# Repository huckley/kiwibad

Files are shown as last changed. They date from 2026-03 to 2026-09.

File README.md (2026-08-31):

# Temperatur Messung im Kiwibad
misst aller halben Stunde die Temperatur und versendet sie via LoRa, export der historischen Daten via BLE ans Smartphone über [phyphox](https://phyphox.org/)
### Sender 
* Vision Master E213
* [GT-U7 GPS-Modul](https://de.aliexpress.com/item/1005001713388717.html)
* [10 Paar 3 Pin SM JST 15 cm Kabel Buchse/Stecker](https://de.aliexpress.com/item/1005006673736507.html)
* 2x [3400 mAh 18650 Lithium-Akku](https://de.aliexpress.com/item/1005007281673163.html)
* [115x90x55mm wasserdichtes Gehäuse](https://de.aliexpress.com/item/1005005631937759.html)
* [SP1710P SP1712S 5 Pin](https://de.aliexpress.com/item/1005006892125866.html)
* [4 18650 Parallele Batteriebox](https://de.aliexpress.com/item/1005001955162216.html)
* [DS18B20 10m](https://de.aliexpress.com/item/1005006090368473.html)
* [DS18B20 1m](https://de.aliexpress.com/item/1005006090368473.html)
### Empfänger
* Heltec WiFi LoRa 32(V3)
* acos-ht4 3dprints are copys from https://www.printables.com/model/1519914-heltec-lora-32-v4v3-pocket-pager-case [CC BY-SA 4.0.]( https://creativecommons.org/licenses/by-sa/4.0/) [@AlleyCat](https://www.printables.com/@AlleyCat)

## Export der historischen Daten am Empfänger
1. [App installieren](https://phyphox.org/)
2. Oben rechts das Plus-Symbol
3. Neues Experiment für Bluetooth-Gerät
4. Kiwibad auswählen
5. auf den Playbutton drücken

## Build instructions

arduino with
* version 2.1.5 of https://github.com/HelTecAutomation/Heltec_ESP32
* https://github.com/Heltec-Aaron-Lee/WiFi_Kit_series [last version has bug](https://github.com/Heltec-Aaron-Lee/WiFi_Kit_series/issues/296)
* Vision Master E213 (sender)
* Heltec WiFi LoRa 32(V3) (receiver)

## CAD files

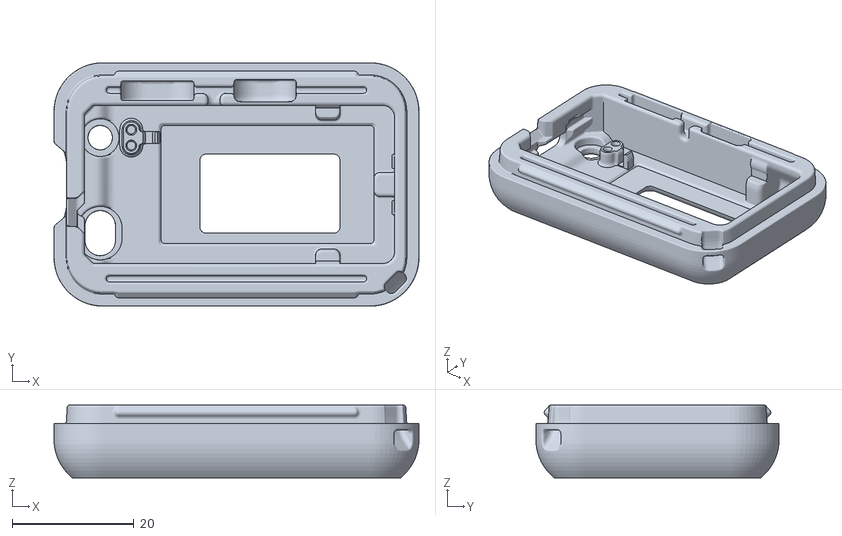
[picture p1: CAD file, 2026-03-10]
3dprint/acos-ht4-pocket-front.stl
60.0 x 40.0 x 12.0

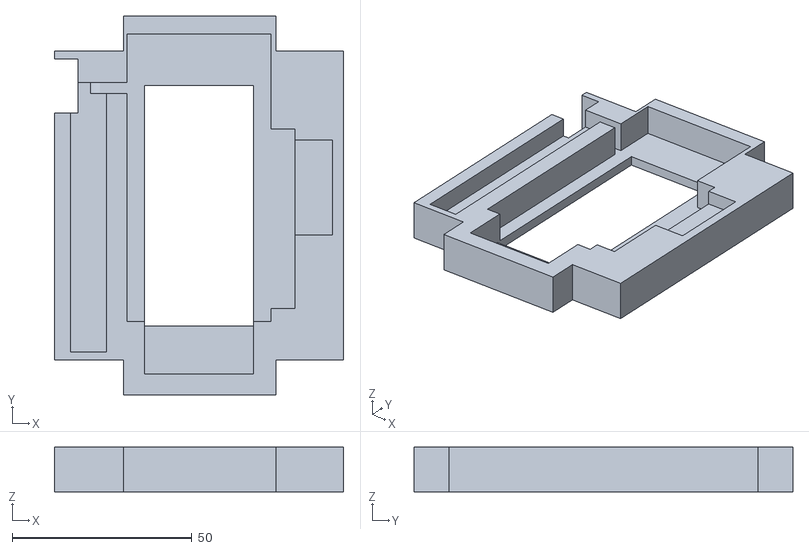
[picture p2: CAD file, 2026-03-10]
3dprint/Kiwigehäuse_front.stl
80.5 x 105.5 x 12.5

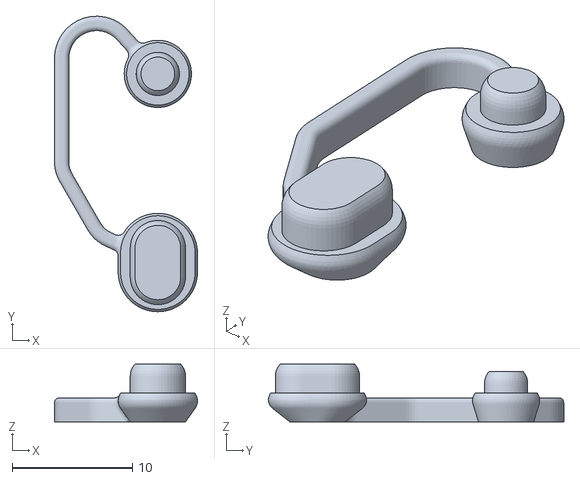
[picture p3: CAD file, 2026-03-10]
3dprint/acos-ht4-buttons.stl
11.9 x 24.6 x 4.80

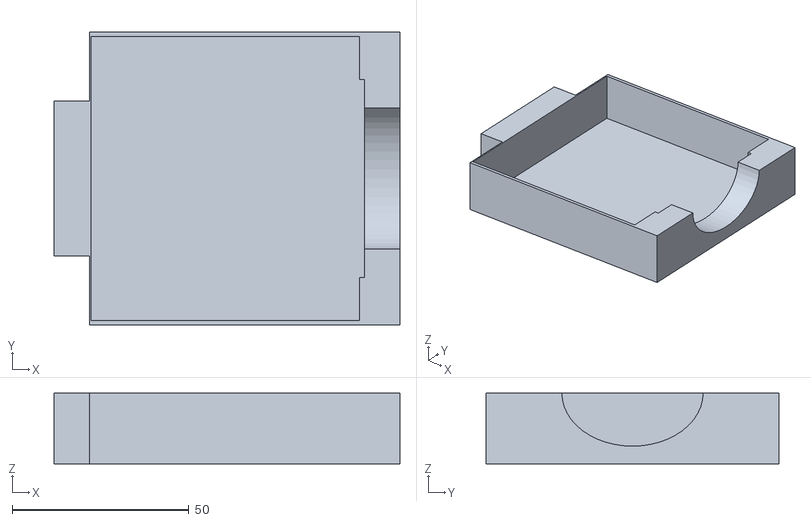
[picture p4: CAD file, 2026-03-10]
3dprint/Kiwigehäuse_bottom.stl
98.0 x 83.0 x 20.0

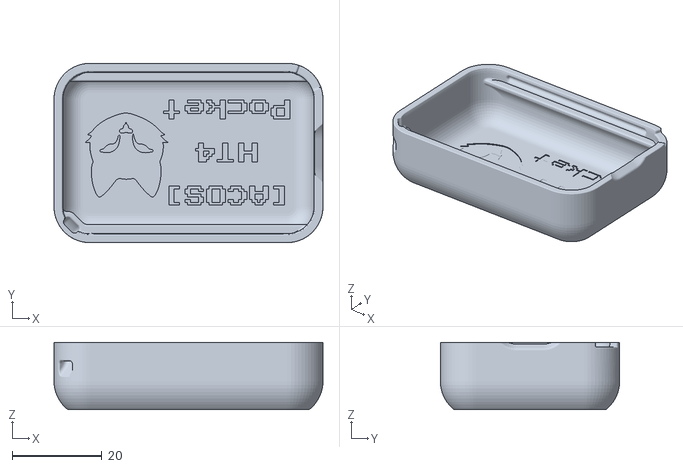
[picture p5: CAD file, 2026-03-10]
3dprint/acos-ht4-pocket-back.stl
60.0 x 40.0 x 15.0

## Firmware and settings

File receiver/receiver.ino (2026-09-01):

#include "LoRaWan_APP.h"
#include "Arduino.h"
#include "HT_SSD1306Wire.h"
#include <time.h>
#include "../secret.h"
#include "../lora.h"
#include "esp_wifi.h"     // ESP32 WiFi control (power saving)
#include "../sensors.h"

// ==== phyphox BLE (nativ, ohne phyphoxBLE-Bibliothek) ====
// Zwei GATT-Services:
//  1) Der offizielle phyphox-Service (UUID cddf0001-...). Wird beworben,
//     damit das Geraet im Bluetooth-Scan von phyphox direkt "weiss"
//     (=unterstuetzt) erscheint. Ueber die Characteristics 0002/0003
//     liefert der Receiver die komplette Experiment-Konfiguration
//     (siehe PHYPHOX_XML unten) automatisch an die App - kein manuelles
//     Laden einer .phyphox-Datei, kein QR-Code noetig.
//     Protokoll: https://phyphox.org/wiki/index.php/Bluetooth_Low_Energy
//     (Abschnitt "Sending phyphox-files from a device")
//  2) Ein eigener Service fuer die eigentlichen Messwerte (6b6a0001-...),
//     auf den die oben gelieferte Konfiguration verweist.
#include <BLEDevice.h>
#include <BLEServer.h>
#include <BLEUtils.h>
#include <BLE2902.h>

#define BLE_DEVICE_NAME "Kiwibad"

#define PHYPHOX_SERVICE_UUID     "cddf0001-30f7-4671-8b43-5e40ba53514a"
#define PHYPHOX_EXPERIMENT_UUID  "cddf0002-30f7-4671-8b43-5e40ba53514a" // liefert die Konfiguration
#define PHYPHOX_CONTROL_UUID     "cddf0003-30f7-4671-8b43-5e40ba53514a" // App schreibt 1 = "sende jetzt"

#define KIWIBAD_DATA_SERVICE_UUID "6b6a0001-1c7c-4d69-9d2b-3a2e6f9a1000"
#define KIWIBAD_DATA_CHAR_UUID    "6b6a0002-1c7c-4d69-9d2b-3a2e6f9a1000"

// Identisch zu Kiwibad.phyphox im Repo (dort nur als lesbares Backup/Referenz -
// diese eingebettete Kopie ist die, die tatsaechlich an die App geschickt wird).
static const char PHYPHOX_XML[] =
R"PHYPHOXFILE(<phyphox version="1.7">
    <title>Kiwibad Temperatur</title>
    <category>Kiwibad</category>
    <color>ff8000</color>
    <description>
        Luft- und Wassertemperatur (je 2 Sensoren) sowie Batteriespannung aus
        dem Kiwibad, per LoRa empfangen. Der Receiver liefert dieses
        Experiment automatisch per Bluetooth mit - kein manuelles Laden
        einer Datei noetig, einfach im Bluetooth-Scan antippen.
        Zeigt zuerst die gespeicherte Historie (bis zu 24 Messungen), danach
        neue Messungen live.
        X-Achse: Uhrzeit in Dezimalstunden (z.B. 8.5 = 08:30 Uhr).
        Ein Sensor, der noch nie gemeldet wurde, liefert -127°C (dieselbe
        Fehlerkonvention wie beim DS18B20-Sensor selbst) - diese Punkte
        werden in den Graphen per Filter entfernt (echte Luecke statt
        Ausreisser).
    </description>

    <data-containers>
        <container size="500">recordTimeHours</container>
        <container size="500">air1Temp</container>
        <container size="500">air2Temp</container>
        <container size="500">water1Temp</container>
        <container size="500">water2Temp</container>
        <container size="500">batteryMilliVolts</container>
        <container size="500">air1TempF</container>
        <container size="500">air1TimeF</container>
        <container size="500">air2TempF</container>
        <container size="500">air2TimeF</container>
        <container size="500">water1TempF</container>
        <container size="500">water1TimeF</container>
        <container size="500">water2TempF</container>
        <container size="500">water2TimeF</container>
    </data-containers>

    <input>
        <bluetooth name="Kiwibad" uuid="cddf0001-30f7-4671-8b43-5e40ba53514a" id="kiwibad" autoConnect="true" mode="notification" subscribeOnStart="false">
            <output char="6b6a0002-1c7c-4d69-9d2b-3a2e6f9a1000" conversion="float32LittleEndian" offset="0" size="4">recordTimeHours</output>
            <output char="6b6a0002-1c7c-4d69-9d2b-3a2e6f9a1000" conversion="int8" offset="4" size="1">air1Temp</output>
            <output char="6b6a0002-1c7c-4d69-9d2b-3a2e6f9a1000" conversion="int8" offset="5" size="1">air2Temp</output>
            <output char="6b6a0002-1c7c-4d69-9d2b-3a2e6f9a1000" conversion="int8" offset="6" size="1">water1Temp</output>
            <output char="6b6a0002-1c7c-4d69-9d2b-3a2e6f9a1000" conversion="int8" offset="7" size="1">water2Temp</output>
            <output char="6b6a0002-1c7c-4d69-9d2b-3a2e6f9a1000" conversion="uInt16LittleEndian" offset="8" size="2">batteryMilliVolts</output>
        </bluetooth>
    </input>

    <analysis>
        <rangefilter>
            <input clear="false">air1Temp</input>
            <input as="min" type="value">-50</input>
            <input as="max" type="value">100</input>
            <input clear="false">recordTimeHours</input>
            <output>air1TempF</output>
            <output>air1TimeF</output>
        </rangefilter>
        <rangefilter>
            <input clear="false">air2Temp</input>
            <input as="min" type="value">-50</input>
            <input as="max" type="value">100</input>
            <input clear="false">recordTimeHours</input>
            <output>air2TempF</output>
            <output>air2TimeF</output>
        </rangefilter>
        <rangefilter>
            <input clear="false">water1Temp</input>
            <input as="min" type="value">-50</input>
            <input as="max" type="value">100</input>
            <input clear="false">recordTimeHours</input>
            <output>water1TempF</output>
            <output>water1TimeF</output>
        </rangefilter>
        <rangefilter>
            <input clear="false">water2Temp</input>
            <input as="min" type="value">-50</input>
            <input as="max" type="value">100</input>
            <input clear="false">recordTimeHours</input>
            <output>water2TempF</output>
            <output>water2TimeF</output>
        </rangefilter>
    </analysis>

    <views>
        <view label="Temperaturverlauf">
            <value label="Uhrzeit" unit="h" precision="2">
                <input>recordTimeHours</input>
            </value>
            <value label="Luft 1" unit="°C" precision="0" color="ff8000">
                <input>air1Temp</input>
            </value>
            <value label="Luft 2" unit="°C" precision="0" color="ffc080">
                <input>air2Temp</input>
            </value>
            <value label="Wasser 1" unit="°C" precision="0" color="0080ff">
                <input>water1Temp</input>
            </value>
            <value label="Wasser 2" unit="°C" precision="0" color="80c0ff">
                <input>water2Temp</input>
            </value>
            <value label="Batteriespannung" unit="mV" precision="0">
                <input>batteryMilliVolts</input>
            </value>

            <separator height="1" />

            <graph label="Lufttemperatur" labelX="Uhrzeit (h)" labelY="Temperatur" unitY="°C" partialUpdate="true">
                <input axis="x" color="ff8000">air1TimeF</input>
                <input axis="y" color="ff8000">air1TempF</input>
                <input axis="x" color="ffc080">air2TimeF</input>
                <input axis="y" color="ffc080">air2TempF</input>
            </graph>

            <graph label="Wassertemperatur" labelX="Uhrzeit (h)" labelY="Temperatur" unitY="°C" partialUpdate="true">
                <input axis="x" color="0080ff">water1TimeF</input>
                <input axis="y" color="0080ff">water1TempF</input>
                <input axis="x" color="80c0ff">water2TimeF</input>
                <input axis="y" color="80c0ff">water2TempF</input>
            </graph>

            <graph label="Batteriespannung" labelX="Uhrzeit (h)" labelY="Spannung" unitY="mV" partialUpdate="true">
                <input axis="x">recordTimeHours</input>
                <input axis="y">batteryMilliVolts</input>
            </graph>
        </view>
    </views>

    <export>
        <set name="Kiwibad Messwerte (roh, inkl. -127 = kein Wert)">
            <data name="Uhrzeit (Dezimalstunden)">recordTimeHours</data>
            <data name="Lufttemperatur 1 (°C)">air1Temp</data>
            <data name="Lufttemperatur 2 (°C)">air2Temp</data>
            <data name="Wassertemperatur 1 (°C)">water1Temp</data>
            <data name="Wassertemperatur 2 (°C)">water2Temp</data>
            <data name="Batteriespannung (mV)">batteryMilliVolts</data>
        </set>
        <set name="Kiwibad Messwerte (gefiltert)">
            <data name="Luft 1 - Uhrzeit">air1TimeF</data>
            <data name="Luft 1 - Temperatur (°C)">air1TempF</data>
            <data name="Luft 2 - Uhrzeit">air2TimeF</data>
            <data name="Luft 2 - Temperatur (°C)">air2TempF</data>
            <data name="Wasser 1 - Uhrzeit">water1TimeF</data>
            <data name="Wasser 1 - Temperatur (°C)">water1TempF</data>
            <data name="Wasser 2 - Uhrzeit">water2TimeF</data>
            <data name="Wasser 2 - Temperatur (°C)">water2TempF</data>
        </set>
    </export>
</phyphox>
)PHYPHOXFILE";

BLEServer *pBleServer = nullptr;
BLECharacteristic *pPhyphoxExperimentChar = nullptr; // 0002: liefert PHYPHOX_XML
BLECharacteristic *pPhyphoxControlChar = nullptr;     // 0003: App schreibt 1 = "sende jetzt"
BLECharacteristic *pKiwibadDataChar = nullptr;        // eigene Messwert-Characteristic
volatile bool bleClientConnected = false;

static BLE2902 phyphoxExperimentCCCD;
static BLE2902 kiwibadDataCCCD;

// === Nicht-blockierendes History-Replay (statt delay(30) in einer Schleife) ===
// tickHistoryReplay() wird aus loop() aufgerufen und schickt pro Aufruf
// hoechstens EINEN Eintrag - der naechste folgt erst wieder, wenn seit dem
// letzten Versand mindestens HISTORY_SEND_INTERVAL_MS vergangen sind.
const unsigned long HISTORY_SEND_INTERVAL_MS = 30;
bool historyReplayActive = false;
int historyReplayIndex = 0;
float historyFillAir[MAX_SENSORS];
float historyFillWater[MAX_SENSORS];
unsigned long historyLastSendTime = 0;

// Fallback, falls der CCCD-Subscribe-Callback aus irgendeinem Grund nicht
// zuverlaessig feuert (variiert je nach ESP32-BLE-Bibliotheksversion):
// solange verbunden, wird die Historie zusaetzlich in einem festen Intervall
// automatisch erneut geschickt - dann klappt es spaetestens danach von selbst,
// ganz ohne Tastendruck.
const unsigned long AUTO_HISTORY_RESEND_INTERVAL_MS = 5000;
unsigned long lastAutoHistorySend = 0;

// === Nicht-blockierende Uebertragung der phyphox-Experiment-Datei ===
const unsigned long FILE_CHUNK_INTERVAL_MS = 20;
const size_t FILE_CHUNK_SIZE = 18; // sicher unter der Standard-BLE-MTU von 20 Byte
volatile bool fileTransferRequested = false; // wird aus der BLE-Callback gesetzt
bool fileTransferActive = false;
bool fileTransferHeaderSent = false;
size_t fileTransferSent = 0;
unsigned long fileTransferLastChunkTime = 0;

// ==== OLED ====
SSD1306Wire oled_display(0x3c, 500000, SDA_OLED, SCL_OLED, GEOMETRY_128_64, RST_OLED);
#include "battery.h"

#define buttonPin 0
volatile bool buttonPressed = false;
unsigned long lastActivityTime = 0;
bool displayOn = true;
const unsigned long DISPLAY_TIMEOUT = 5 * 60 * 1000; // 5 Minuten in ms
volatile unsigned long lastButtonTime = 0; // Zeitstempel für Entprellung
const unsigned long DEBOUNCE_DELAY = 250; // 250ms Sperrzeit

// ISR für den Button
void IRAM_ATTR handleButton() {
  unsigned long currentTime = millis();
  // Nur akzeptieren, wenn der letzte Klick länger als DEBOUNCE_DELAY her ist
  if (currentTime - lastButtonTime > DEBOUNCE_DELAY) {
    buttonPressed = true;
    lastButtonTime = currentTime;
  }
}

typedef enum {
  LOWPOWER,
  STATE_RX
} States_t;
States_t state;

struct Measurement {
  uint8_t address1;
  uint8_t address2;
  uint8_t hour;
  uint8_t minute;
  float temperature1;
  float temperature2;
  float batteryVoltage;
};

const int MAX_ENTRIES = 24;
Measurement rrdBuffer[MAX_ENTRIES];
int head = 0;
int displayhead = 0;

void VextON() {
  pinMode(Vext, OUTPUT);
  digitalWrite(Vext, LOW);
}

void VextOFF() {
  pinMode(Vext, OUTPUT);
  digitalWrite(Vext, HIGH);
}

// === Sensor-Rohwerte den einzelnen physischen Sensoren zuordnen ===
// sensors.h definiert MAX_SENSORS (=2) Luft- UND 2 Wassersensoren mit fester
// Adresse. Ein LoRa-Paket trägt immer nur zwei Messwerte (addr1/temp1,
// addr2/temp2), aber über mehrere Pakete hinweg können unterschiedliche
// Sensoren gemeldet werden. Deshalb hier NICHT auf ein gemeinsames
// "airTemp"/"waterTemp" zusammenfassen, sondern jedem
// air_sensor_addr[i] / water_sensor_addr[i] seinen eigenen Kanal geben.
// Nicht in diesem Paket enthaltene Sensoren bleiben NAN.
void classifySensors(uint8_t addr1, uint8_t addr2, float temp1, float temp2,
                      float airTemps[MAX_SENSORS], float waterTemps[MAX_SENSORS]) {
  for (int i = 0; i < MAX_SENSORS; i++) {
    airTemps[i] = NAN;
    waterTemps[i] = NAN;
  }
  for (int i = 0; i < MAX_SENSORS; i++) {
    uint8_t airAddr = getshortaddr(air_sensor_addr[i]);
    if (addr1 == airAddr) airTemps[i] = temp1;
    if (addr2 == airAddr) airTemps[i] = temp2;

    uint8_t waterAddr = getshortaddr(water_sensor_addr[i]);
    if (addr1 == waterAddr) waterTemps[i] = temp1;
    if (addr2 == waterAddr) waterTemps[i] = temp2;
  }
}

// Ersten nicht-NAN Wert aus einem Array zurückgeben (fürs kleine OLED-Display,
// das nur Platz für einen einzelnen "L:"/"W:"-Wert hat)
float firstValid(float values[MAX_SENSORS]) {
  for (int i = 0; i < MAX_SENSORS; i++) {
    if (!isnan(values[i])) return values[i];
  }
  return NAN;
}

// === Einen Messpunkt an phyphox schicken ===
// Ein Paket, 10 Byte, little endian (siehe Kiwibad.phyphox):
//   Byte 0-3: Uhrzeit in Dezimalstunden (float32)
//   Byte 4  : Lufttemperatur 1, ganze °C (int8) - oder -127, wenn dieser
//             Sensor noch nie gemeldet wurde (dieselbe Fehlerkonvention wie
//             beim DS18B20 selbst, siehe OnRxDone weiter unten)
//   Byte 5  : Lufttemperatur 2, ganze °C (int8, -127 = kein Wert)
//   Byte 6  : Wassertemperatur 1, ganze °C (int8, -127 = kein Wert)
//   Byte 7  : Wassertemperatur 2, ganze °C (int8, -127 = kein Wert)
//   Byte 8-9: Batteriespannung in mV (uInt16)
const int8_t PHYPHOX_NO_VALUE = -127;

void sendMeasurementToPhyphox(uint16_t recordTime, float airTemps[MAX_SENSORS],
                               float waterTemps[MAX_SENSORS], float batV) {
  if (!bleClientConnected || pKiwibadDataChar == nullptr) {
    Serial.println("phyphox-Messwert NICHT gesendet: kein BLE-Client verbunden");
    return;
  }

  float recordTimeHoursF = (float)recordTime / 60.0f;

  int8_t airVals[MAX_SENSORS];
  int8_t waterVals[MAX_SENSORS];
  for (int s = 0; s < MAX_SENSORS; s++) {
    airVals[s]   = isnan(airTemps[s])   ? PHYPHOX_NO_VALUE : (int8_t)lroundf(airTemps[s]);
    waterVals[s] = isnan(waterTemps[s]) ? PHYPHOX_NO_VALUE : (int8_t)lroundf(waterTemps[s]);
  }
  uint16_t battMv = (uint16_t)lroundf(batV * 1000.0f);

  uint8_t packet[10];
  memcpy(&packet[0], &recordTimeHoursF, sizeof(float));
  packet[4] = (uint8_t)airVals[0];
  packet[5] = (uint8_t)airVals[1];
  packet[6] = (uint8_t)waterVals[0];
  packet[7] = (uint8_t)waterVals[1];
  packet[8] = battMv & 0xFF;
  packet[9] = (battMv >> 8) & 0xFF;

  pKiwibadDataChar->setValue(packet, sizeof(packet));
  pKiwibadDataChar->notify();

  Serial.printf("phyphox-Messwert gesendet: t=%.2f h, Luft1=%d Luft2=%d Wasser1=%d Wasser2=%d C, Batt=%u mV\n",
                recordTimeHoursF, airVals[0], airVals[1], waterVals[0], waterVals[1], battMv);
}

// === Kompletten Ringpuffer (älteste zuerst) an phyphox schicken ===
// Ein LoRa-Paket liefert immer nur 2 der 4 Sensoren - deshalb wird hier beim
// Durchlaufen fortgeschrieben (letzter bekannter Wert bleibt stehen, statt
// bei jedem Eintrag auf 2 von 4 Linien eine Lücke zu erzeugen).
//
// Nicht-blockierend: startHistoryReplay() setzt nur den Startzustand,
// tickHistoryReplay() (aus loop() aufgerufen) schickt pro Aufruf höchstens
// einen Eintrag und pausiert dazwischen per millis()-Vergleich statt delay().
void startHistoryReplay() {
  for (int s = 0; s < MAX_SENSORS; s++) {
    historyFillAir[s] = NAN;
    historyFillWater[s] = NAN;
  }
  historyReplayIndex = 0;
  historyReplayActive = true;
  historyLastSendTime = 0; // naechster tick darf sofort senden
}
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
void loop() {
  // Fallback-Trigger: alle paar Sekunden automatisch erneut senden, solange
  // verbunden - unabhaengig davon, ob der CCCD-Subscribe-Callback zuverlaessig
  // gefeuert hat. Kein delay(): reiner millis()-Vergleich.
  if (bleClientConnected && !historyReplayActive &&
      (millis() - lastAutoHistorySend >= AUTO_HISTORY_RESEND_INTERVAL_MS)) {
    startHistoryReplay();
    lastAutoHistorySend = millis();
  }

  if (buttonPressed) {
    buttonPressed = false;
    lastActivityTime = millis(); // Timer resetten

    if (!displayOn) {
      VextON();
      oled_display.init();
      displayOn = true;
    } else {
      // Rückwärts durch den Buffer blättern
      displayhead = (displayhead - 1 + MAX_ENTRIES) % MAX_ENTRIES;
    }
    updateDisplay(displayhead);
    startHistoryReplay(); // Taste dient auch als manuelles "jetzt an phyphox senden"
  }

  // Nicht-blockierende BLE-Zustandsautomaten - schicken pro Aufruf höchstens
  // ein Paket und kehren sofort zurück, kein delay() irgendwo im Ablauf.
  tickHistoryReplay();
  tickPhyphoxFileTransfer();

  // 2. Timeout Check (Display aus nach 5 Min)
  /*
  if (displayOn && (millis() - lastActivityTime > DISPLAY_TIMEOUT)) {
    oled_display.clear();
    oled_display.display();
    // Vext ausschalten spart am Heltec Board am meisten Strom
    VextOFF();
    displayOn = false;
  }
  */

  switch (state) {
    case STATE_RX:
      Radio.Rx(0); // Listen for packets
      state = LOWPOWER;
      break;
    case LOWPOWER:
      Radio.IrqProcess(); // Check LoRa events
      break;
    default:
      break;
  }
}

// === OLED Display Update ===
void updateDisplay(int myhead) {
  char lineBuf[48];
  snprintf(lineBuf, sizeof(lineBuf), "Time: %02u:%02u|%u %u",
           rrdBuffer[myhead].hour, rrdBuffer[myhead].minute,
           rrdBuffer[myhead].address1, rrdBuffer[myhead].address2);

  oled_display.clear();
  oled_display.setFont(ArialMT_Plain_10);
  oled_display.drawString(0, 0, lineBuf);
  battery();

  oled_display.setFont(ArialMT_Plain_24);

  float airTemps[MAX_SENSORS], waterTemps[MAX_SENSORS];
  classifySensors(rrdBuffer[myhead].address1, rrdBuffer[myhead].address2,
                   rrdBuffer[myhead].temperature1, rrdBuffer[myhead].temperature2,
                   airTemps, waterTemps);
  // Kleines Display hat nur Platz für je eine Zeile -> ersten gemeldeten
  // Sensor der Kategorie zeigen (die vollen 4 Kanäle sieht man in phyphox)
  float airTempC = firstValid(airTemps);
  float waterTempC = firstValid(waterTemps);

  char airBuf[16];
  char waterBuf[16];
  if (isnan(airTempC)) {
    snprintf(airBuf, sizeof(airBuf), "L: --°C");
  } else {
    snprintf(airBuf, sizeof(airBuf), "L: %.1f°C", airTempC);
  }
  if (isnan(waterTempC)) {
    snprintf(waterBuf, sizeof(waterBuf), "W: --°C");
  } else {
    snprintf(waterBuf, sizeof(waterBuf), "W: %.1f°C", waterTempC);
  }

  oled_display.drawString(0, 10, airBuf);
  oled_display.drawString(0, 34, waterBuf);
  oled_display.display();
}

void storeData(uint8_t addr1, uint8_t addr2, uint8_t hour, uint8_t minute, float temp1, float temp2, float batV) {
  rrdBuffer[head].hour = hour;
  rrdBuffer[head].minute = minute;
  rrdBuffer[head].address1 = addr1;
  rrdBuffer[head].address2 = addr2;
  rrdBuffer[head].temperature1 = temp1;
  rrdBuffer[head].temperature2 = temp2;
  rrdBuffer[head].batteryVoltage = batV;

  displayhead = head;
  head = (head + 1) % MAX_ENTRIES;
}

// === LoRa Packet Received ===
void OnRxDone(uint8_t *payload, uint16_t size, int16_t rssi, int8_t snr) {
  Radio.Sleep();

  // Validate size
  if (size != PAYLOAD_LEN) {
    Serial.println("Invalid payload length");
    state = STATE_RX;
    return;
  }

  // Copy payload to local buffer if needed
  uint8_t packet[PAYLOAD_LEN];
  memcpy(packet, payload, size);

  // Optional: debug raw payload
  Serial.print("Raw payload: ");
  for (int i = 0; i < size; i++) {
    Serial.printf("%02X ", packet[i]);
  }
  Serial.println();

  // === VERIFY HMAC ===
  if (!verifyHMACSignatureBinary(packet)) {
    Serial.println("Invalid signature - ignoring packet");
    state = STATE_RX;
    return;
  }

  // === PARSE PAYLOAD ===
  uint8_t sensorID1 = packet[0];
  uint8_t sensorID2 = packet[1];
  uint8_t hour = packet[2];
  uint8_t minute = packet[3];

  uint16_t batteryRaw = (packet[4] << 8) | packet[5];
  float batteryVoltage = batteryRaw / 1000.0f;

  uint16_t temp1Raw = (packet[6] << 8) | packet[7];
  float temp1 = (temp1Raw == 0xFFFF) ? NAN : (temp1Raw / 10.0f) - 40.0f;

  uint16_t temp2Raw = (packet[8] << 8) | packet[9];
  float temp2 = (temp2Raw == 0xFFFF) ? NAN : (temp2Raw / 10.0f) - 40.0f;

  storeData(sensorID1, sensorID2, hour, minute, temp1, temp2, batteryVoltage);

  // === Neue Historie an phyphox schicken (inkl. dieser neuen Messung) ===
  startHistoryReplay();

  // === OUTPUT ===
  Serial.println("---- LoRa Packet Received ----");
  Serial.printf("SensorID: %02X:%02X\n", sensorID1, sensorID2);
  Serial.printf("Time : %02d:%02d\n", hour, minute);
  Serial.printf("Battery: %.3f V\n", batteryVoltage);
  if (isnan(temp1)) {
    Serial.println("Temp1 : -127");
  } else {
    Serial.printf("Temp1 : %.1f\n", temp1);
  }
  if (isnan(temp2)) {
    Serial.println("Temp2 : -127");
  } else {
    Serial.printf("Temp2 : %.1f\n", temp2);
  }

  if (!displayOn) {
    VextON();
    oled_display.init();
    displayOn = true;
  }
  lastActivityTime = millis();
  updateDisplay(displayhead);
  state = STATE_RX;
}

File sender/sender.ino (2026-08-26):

#include <time.h>
#include "Arduino.h"
#include "LoRaWan_APP.h"
#include "HT_lCMEN2R13EFC1.h"
#include <driver/gpio.h>
#include <driver/rtc_io.h>
#include <HardwareSerial.h>
#include "HT_TinyGPS++.h"
#include "HT_E0213A367.h"
#include "driver/board-config.h"
#include "Monospaced_bold_50.h"
#include "esp_bt.h"                 // ESP32 Bluetooth control (power saving)
#include "esp_wifi.h"               // ESP32 WiFi control (power saving)

ScreenDisplay *epaper_display;
#include "battery.h"
#include "../secret.h"
#include "../lora.h"
#include "../sensors.h"

// ===============================
// ONE WIRE Configuration
// ===============================

#define ONE_WIRE_BUS 17
#define TEMPERATURE_PRECISION 9
OneWire oneWire(ONE_WIRE_BUS);
DallasTemperature sensors(&oneWire);

DeviceAddress sensorAddresses[MAX_SENSORS];
int deviceCount = 0;
float airTempC = -127;
float waterTempC = -127;
uint8_t sensorIDs[] = {0, 0};
float temps[] = {-127,-127};

uint32_t joinStartTime = 0;

#define LED  45
#define PIN_EINK_SCLK 4
#define PIN_EINK_DC   2
#define PIN_EINK_CS   5
#define PIN_EINK_RES  3
#define PIN_EINK_MOSI 6

#define SLEEP_TIME   1800 // Sleep time in seconds
#define WAKEUP_HOUR 8     // at which hour we wakup
#define NIGHT_HOUR  20    // after which hour we sleep for the night
#define GPS_RX 43 
#define GPS_TX 44
#define GPS_BAUD 9600
#define GPS_TIMEOUT_MS 180000  // Max wait for GPS (3 min)
#define TZ_INFO "CET-1CEST,M3.5.0/2,M10.5.0/3"  // Timezone string
TinyGPSPlus GPS;

RTC_DATA_ATTR int64_t epoch_base = 0;  // Full 64-bit epoch time
RTC_DATA_ATTR bool send_on_lora = true;

void VextON(void) {
  pinMode(18, OUTPUT);
  digitalWrite(18, HIGH);
  pinMode(46, OUTPUT);
  digitalWrite(46, HIGH);
}

void VextOFF(void) {
  pinMode(18, OUTPUT);
  digitalWrite(18, LOW);
  pinMode(46, OUTPUT);
  digitalWrite(46, LOW);
}

void enterDeepSleepForseconds(uint32_t seconds) {
  VextOFF();

  // Prepare peripherals
  Radio.Sleep();         // Put LoRa radio to sleep
  SPI.end();             // End SPI to save power

  // Set other unused pins to analog to minimize leakage
  pinMode(RADIO_DIO_1, ANALOG);
  pinMode(RADIO_RESET, ANALOG);
  pinMode(RADIO_BUSY, ANALOG);
  pinMode(LORA_CLK, ANALOG);
  pinMode(LORA_MISO, ANALOG);
  pinMode(LORA_MOSI, ANALOG);

  struct timeval tv_now;
  gettimeofday(&tv_now, nullptr);  // get current system time
  time_t now = tv_now.tv_sec;
  struct tm *timeinfo = localtime(&now);

  epoch_base = (int64_t)now + seconds ;    // save seconds part to RTC memory
  if (timeinfo->tm_hour > NIGHT_HOUR) {
    struct tm target_tm = *timeinfo;
    target_tm.tm_hour = WAKEUP_HOUR;
    target_tm.tm_min = (sensorIDs[0]+sensorIDs[1]) % 60;
    target_tm.tm_sec = esp_random() % 60;
    
    time_t target_time = mktime(&target_tm);
    if (target_time <= now) {
      target_time += 24 * 3600;
    }
    seconds = (uint64_t)(target_time - now);
    epoch_base = 0;
  }
  Serial.printf("Wakeup time to RTC: %lld\n", epoch_base);
  Serial.printf("going to sleep for %u sec...\n", seconds);
  Serial.flush();
  // send_on_lora = !send_on_lora;
  esp_sleep_enable_timer_wakeup((uint64_t)seconds  * 1000000ULL);
  esp_deep_sleep_start();
}

void init_display() {
  pinMode(PIN_EINK_SCLK, OUTPUT);
  pinMode(PIN_EINK_DC, OUTPUT);
  pinMode(PIN_EINK_CS, OUTPUT);
  pinMode(PIN_EINK_RES, OUTPUT);

  // rest e-ink
  digitalWrite(PIN_EINK_RES, LOW);
  delay(20);
  digitalWrite(PIN_EINK_RES, HIGH);
  delay(20);

  digitalWrite(PIN_EINK_DC, LOW);
  digitalWrite(PIN_EINK_CS, LOW);

  // write cmd
  uint8_t cmd = 0x2F;
  pinMode(PIN_EINK_MOSI, OUTPUT);
  digitalWrite(PIN_EINK_SCLK, LOW);
  for (int i = 0; i < 8; i++) {
    digitalWrite(PIN_EINK_MOSI, (cmd & 0x80) ? HIGH : LOW);
    cmd <<= 1;
    digitalWrite(PIN_EINK_SCLK, HIGH);
    delayMicroseconds(1);
    digitalWrite(PIN_EINK_SCLK, LOW);
    delayMicroseconds(1);
  }
  delay(10);

  digitalWrite(PIN_EINK_DC, HIGH);
  pinMode(PIN_EINK_MOSI, INPUT_PULLUP);

  // read chip ID
  uint8_t chipId = 0;
  for (int8_t b = 7; b >= 0; b--) {
    digitalWrite(PIN_EINK_SCLK, LOW);
    delayMicroseconds(1);
    digitalWrite(PIN_EINK_SCLK, HIGH);
    delayMicroseconds(1);
    if (digitalRead(PIN_EINK_MOSI)) chipId |= (1 << b);
  }
  digitalWrite(PIN_EINK_CS, HIGH);
  if ((chipId &0x03) !=0x01) {
    epaper_display = new HT_ICMEN2R13EFC1(3, 2, 5, 1, 4, 6, -1, 6000000);  // rst,dc,cs,busy,sck,mosi,miso,frequency
  } else {
    epaper_display = new HT_E0213A367(3, 2, 5, 1, 4, 6, -1, 6000000);  // rst,dc,cs,busy,sck,mosi,miso,frequency
  }
  epaper_display->init();
  epaper_display->setFont(ArialMT_Plain_10);
  epaper_display->setTextAlignment(TEXT_ALIGN_LEFT);
}

void Navigation_bar(float airtempC) {
  setenv("TZ", TZ_INFO, 1);
  tzset();
  struct tm timeinfo;
  getLocalTime(&timeinfo);
  char buffer[32];
  strftime(buffer, sizeof(buffer), "%H:%M  %d.%m.%Y", &timeinfo);
  epaper_display->setTextAlignment(TEXT_ALIGN_LEFT);
  epaper_display->setFont(ArialMT_Plain_10);
  epaper_display->drawLine(0, 15, 250, 15);
  String line_one = "Luft: " + String(airtempC, 1) + "°C | " + buffer;
  Serial.println(line_one);
  epaper_display->drawString(0, 0, line_one);
  epaper_display->drawString(0, 111, url);
  battery();
}

void update_display() {
  epaper_display->update(BLACK_BUFFER);
  epaper_display->display();
}

void flash_led() {
  pinMode(LED, OUTPUT);
  digitalWrite(LED, HIGH);
  delay(200);  // LED on for 200 ms
  digitalWrite(LED, LOW);
}

void synctime_from_gps() {
  Serial.println("🛰️  Syncing time from GPS...");
  Serial1.begin(GPS_BAUD, SERIAL_8N1, GPS_RX, GPS_TX);
  uint32_t start = millis();
  bool synced = false;

  while (millis() - start < GPS_TIMEOUT_MS) {
    while (Serial1.available() > 0) {
      GPS.encode(Serial1.read());
        if ( GPS.time.isUpdated() && GPS.date.isUpdated() && GPS.time.isValid() && GPS.date.isValid() ) {
         struct tm t;
          t.tm_year = GPS.date.year() - 1900;
          t.tm_mon  = GPS.date.month() - 1;
          t.tm_mday = GPS.date.day();
          t.tm_hour = GPS.time.hour();
          t.tm_min  = GPS.time.minute();
          t.tm_sec  = GPS.time.second();
          t.tm_isdst = -1;

          time_t gpsEpoch = mktime(&t);
          if (gpsEpoch > 1760817666) {
            struct timeval tv = { .tv_sec = gpsEpoch };
            settimeofday(&tv, nullptr);
            epoch_base = (int64_t)gpsEpoch;
            Serial.println("✅ GPS time synced:");
            synced = true;
            break;
          }
        }
    }
    if (synced) break;
  }
  if (!synced) {
      Serial.println(GPS.charsProcessed());
      Serial.println("⚠️ GPS sync failed. Continuing with estimated time.");
  }
}
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

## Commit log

2025-10-13 Battery läuft
2025-10-15 temp sensor funktioniert
2025-10-17 battery: using case instead of that if /else mess
2025-10-17 flash led on bootup
2025-10-17 Fix: measure the temps only once
    [sender.ino]
2025-10-17 Fix: more stuff depends on send_on_lora
    [sender.ino]
2026-02-26 add 3d print
    [Kiwigehäuse.stl]
2026-02-28 Fix: battery messurment
2026-03-07 New: sender supports multiple sensors
2026-03-08 fix: both temps are have one digit
    [sender.ino]
2026-03-08 New: sensors will get its own h file
2026-03-08 Rewrite reciver to mutiple sensores
2026-03-08 revert old batteray code
    [receiver.ino]
2026-03-10 add 3d prints
    [Kiwigehäuse.stl, Kiwigehäuse_bottom.stl, Kiwigehäuse_front.stl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]
2026-03-16 FIX: wakeuptime is based on sensor address
    [sender.ino]
2026-03-16 Fix: ini battery voltage is also nan, and h & m are displayed with 2 digits
    [battery.h, receiver.ino]
2026-09-01 switch to line graphs
